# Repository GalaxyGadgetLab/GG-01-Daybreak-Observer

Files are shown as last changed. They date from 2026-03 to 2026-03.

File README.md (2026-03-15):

# 銀河ガジェット1号：黎明の観測者(Daybreak Observer)

>共に夜明けと新時代の幕開けを観測しようじゃないかッ!

## 概要
スピーカを搭載した親機を枕元に，停止用RFIDリーダを備えた子機をリビングに設置します．
アラーム時刻の設定は，同一ネットワーク内のデバイスからブラウザ経由で親機のWebサーバーへアクセスして行います．
リビングまで移動してラボの会員証(RFIDタグ)をかざさない限り，アラームは止まりません．

## 構成
## ハードウェア

### 親機(Parent Unit)
| Function | Component / Module | Interface |
| :--- | :--- | :--- |
| MCU | ESP32-WROOM-32E | - |
| Audio | DFPlayer Mini | UART |
| RTC | DS3231  | I2C |
| Display | 2.8"TFT(ILI9341) | SPI |

### 子機(Child Unit)
| Function | Component / Module | Interface |
| :--- | :--- | :--- |
| MCU | ESP32-WROOM-32E | - |
| RFID | MFRC522 (NFC Reader/Writer) | SPI |
| Indicator | High-brightness Red LED | GPIO |
| Alarm | Piezoelectric Buzzer | GPIO |

## PCB設計
本プロジェクトでは，専用のカスタム基板を設計・製作しました．
- **Design Tool：** KiCad 9.0
- **Layer:** 2 Layers

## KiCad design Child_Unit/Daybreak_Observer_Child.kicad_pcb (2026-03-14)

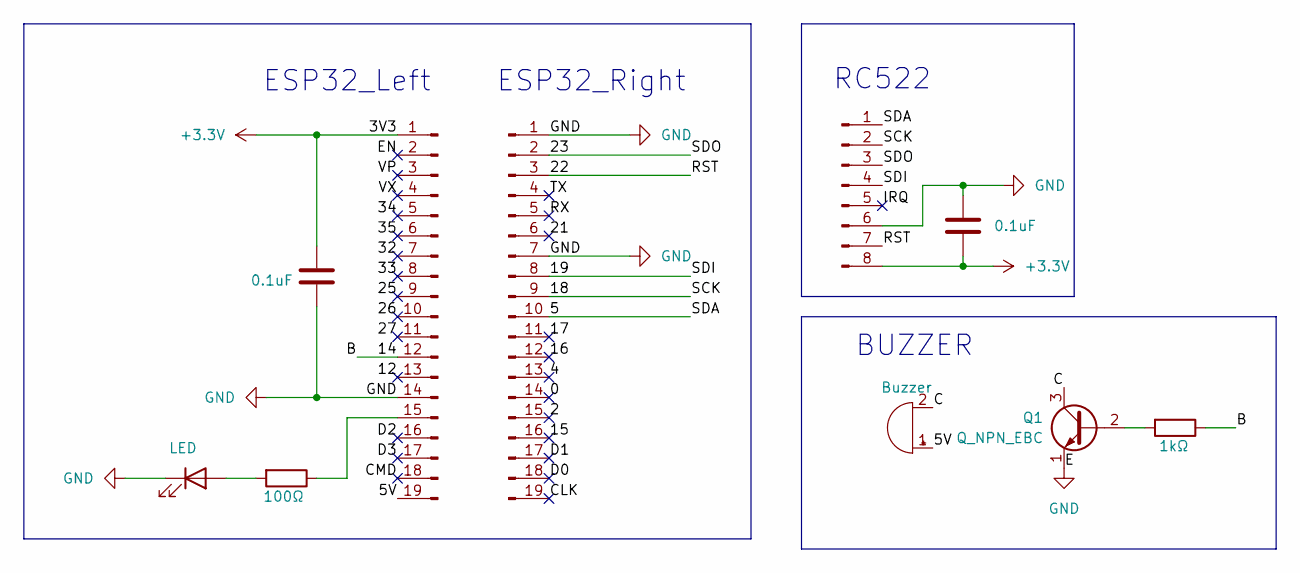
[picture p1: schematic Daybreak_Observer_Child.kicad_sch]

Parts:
BZ1: Buzzer; Buzzer_12x9.5RM7.6
C1, C2: 0.1uF; C_Disc_D5.0mm_W2.5mm_P2.50mm
D1: LED; LED_D3.0mm
J1, J2: Conn_01x19_Pin; PinSocket_1x19_P2.54mm_Vertical
J3: Conn_01x08_Pin; PinSocket_1x08_P2.54mm_Vertical
Q1: Q_NPN_EBC; TO-92_Inline
R2: 100Ω; R_Axial_DIN0207_L6.3mm_D2.5mm_P7.62mm_Horizontal
R3: 1kΩ; R_Axial_DIN0207_L6.3mm_D2.5mm_P7.62mm_Horizontal

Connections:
+3.3V: C1.1, C2.2, J1.1, J3.8
/0: J2.14
/2: J2.15
/4: J2.13
/5: J2.10, J3.1
/5V: BZ1.1 (+), J1.19
/12: J1.13
/14: J1.12, R3.1
/15: J2.16
/16: J2.12
/17: J2.11
/18: J2.9, J3.2
/19: J2.8, J3.4
/21: J2.6
/22: J2.3, J3.7
/23: J2.2, J3.3
/25: J1.9
/26: J1.10
/27: J1.11
/32: J1.7
/33: J1.8
/34: J1.5
/35: J1.6
/C: BZ1.2 (-), Q1.3 (C)
/CLK: J2.19
/CMD: J1.18
/D0: J2.18
/D1: J2.17
/D2: J1.16
/D3: J1.17
/EN: J1.2
/IRQ: J3.5
/RX: J2.5
/TX: J2.4
/VP: J1.3
/VX: J1.4
GND: C1.2, C2.1, D1.1 (K), J1.14, J2.1, J2.7, J3.6, Q1.1 (E)
unnamed: D1.2 (A), R2.2
unnamed: J1.15, R2.1
unnamed: Q1.2 (B), R3.2

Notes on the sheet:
RC522
BUZZER
ESP32_Left
ESP32_Right

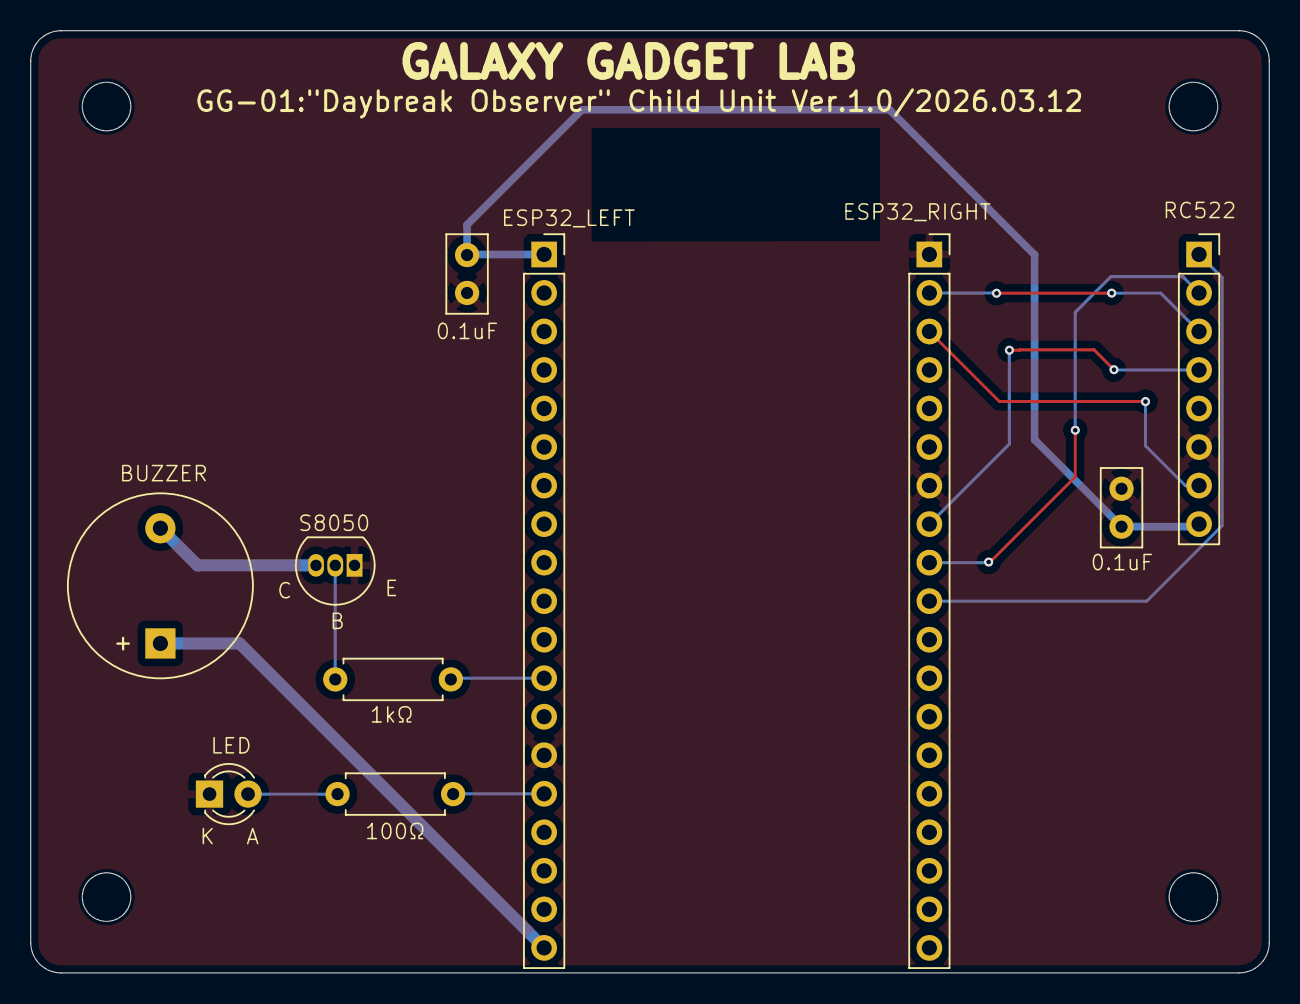
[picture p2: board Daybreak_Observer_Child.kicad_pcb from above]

Board: 2 copper layers, 81.7 x 62.1 mm, 10 parts (0 on the bottom side), 13 nets.

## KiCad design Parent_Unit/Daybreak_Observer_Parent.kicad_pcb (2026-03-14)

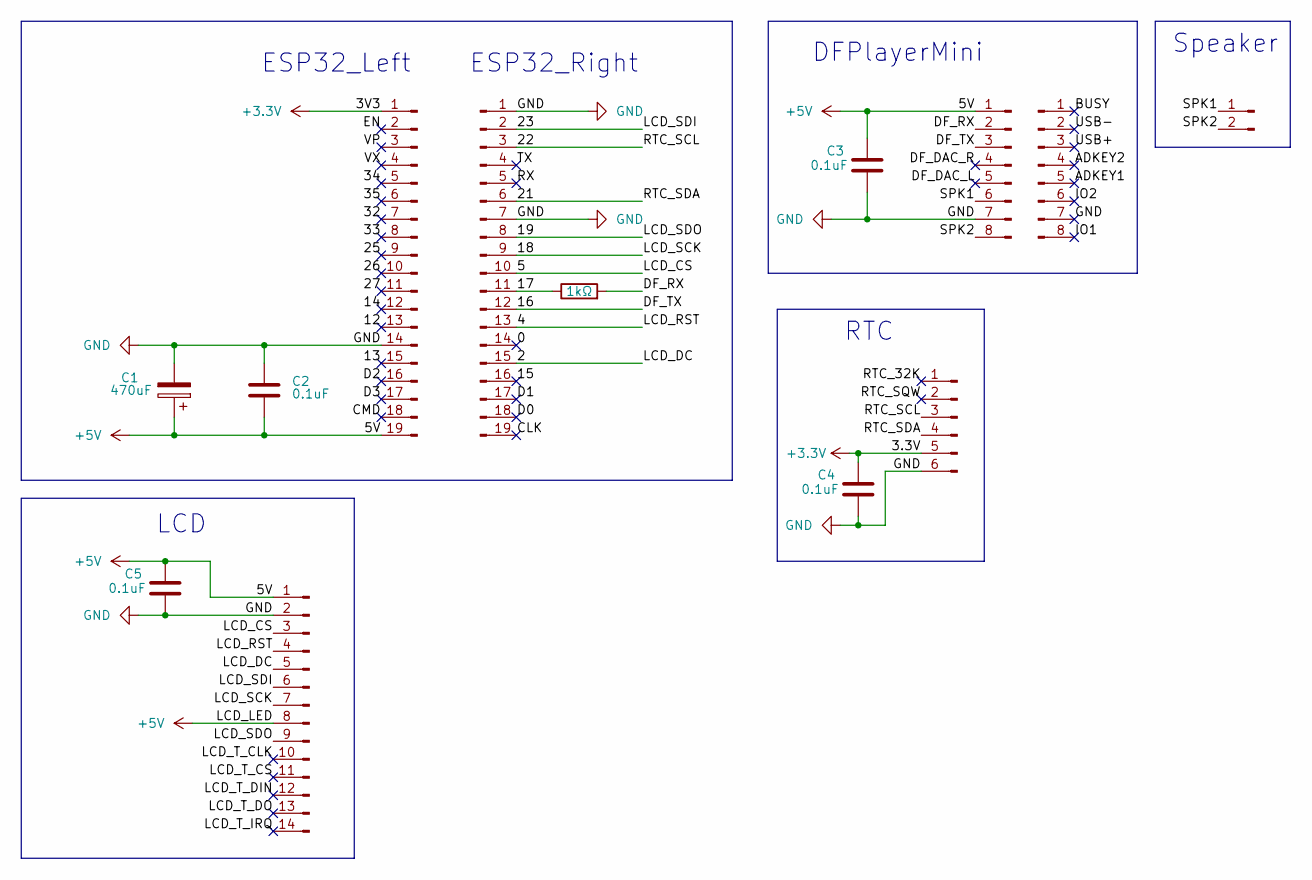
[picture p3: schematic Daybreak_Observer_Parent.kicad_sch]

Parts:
C1: 470uF; CP_Radial_D6.3mm_P2.50mm
C2, C3, C4, C5: 0.1uF; C_Disc_D5.0mm_W2.5mm_P2.50mm
J1, J2: Conn_01x19_Pin; PinSocket_1x19_P2.54mm_Vertical
J3, J4: Conn_01x08_Pin; PinSocket_1x08_P2.54mm_Vertical
J5: Conn_01x06_Pin; PinSocket_1x06_P2.54mm_Vertical
J6: Conn_01x14_Pin; PinSocket_1x14_P2.54mm_Vertical
J7: Conn_01x02_Pin; JST_PH_B2B-PH-K_1x02_P2.00mm_Vertical
R1: 1kΩ; R_Axial_DIN0207_L6.3mm_D2.5mm_P7.62mm_Horizontal

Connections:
+3.3V: C4.1, J1.1, J5.5
+5V: C1.1, C2.2, C3.1, C5.1, J1.19, J3.1, J6.1, J6.8
/0: J2.14
/2: J2.15, J6.5
/4: J2.13, J6.4
/5: J2.10, J6.3
/12: J1.13
/13: J1.15
/14: J1.12
/15: J2.16
/16: J2.12, J3.3
/17: J2.11, R1.1
/18: J2.9, J6.7
/19: J2.8, J6.9
/21: J2.6, J5.4
/22: J2.3, J5.3
/23: J2.2, J6.6
/25: J1.9
/26: J1.10
/27: J1.11
/32: J1.7
/33: J1.8
/34: J1.5
/35: J1.6
/ADKEY1: J4.5
/ADKEY2: J4.4
/BUSY: J4.1
/CLK: J2.19
/CMD: J1.18
/D0: J2.18
/D1: J2.17
/D2: J1.16
/D3: J1.17
/DF_DAC_L: J3.5
/DF_DAC_R: J3.4
/DF_RX: J3.2, R1.2
/EN: J1.2
/IO1: J4.8
/IO2: J4.6
/LCD_T_CLK: J6.10
/LCD_T_CS: J6.11
/LCD_T_DIN: J6.12
/LCD_T_DO: J6.13
/LCD_T_IRQ: J6.14
/RTC_32K: J5.1
/RTC_SQW: J5.2
/RX: J2.5
/SPK1: J3.6, J7.1
/SPK2: J3.8, J7.2
/TX: J2.4
/USB+: J4.3
/USB-: J4.2
/VP: J1.3
/VX: J1.4
GND: C1.2, C2.1, C3.2, C4.2, C5.2, J1.14, J2.1, J2.7, J3.7, J4.7, J5.6, J6.2

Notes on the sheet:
LCD
ESP32_Left
Speaker
RTC
ESP32_Right
DFPlayerMini

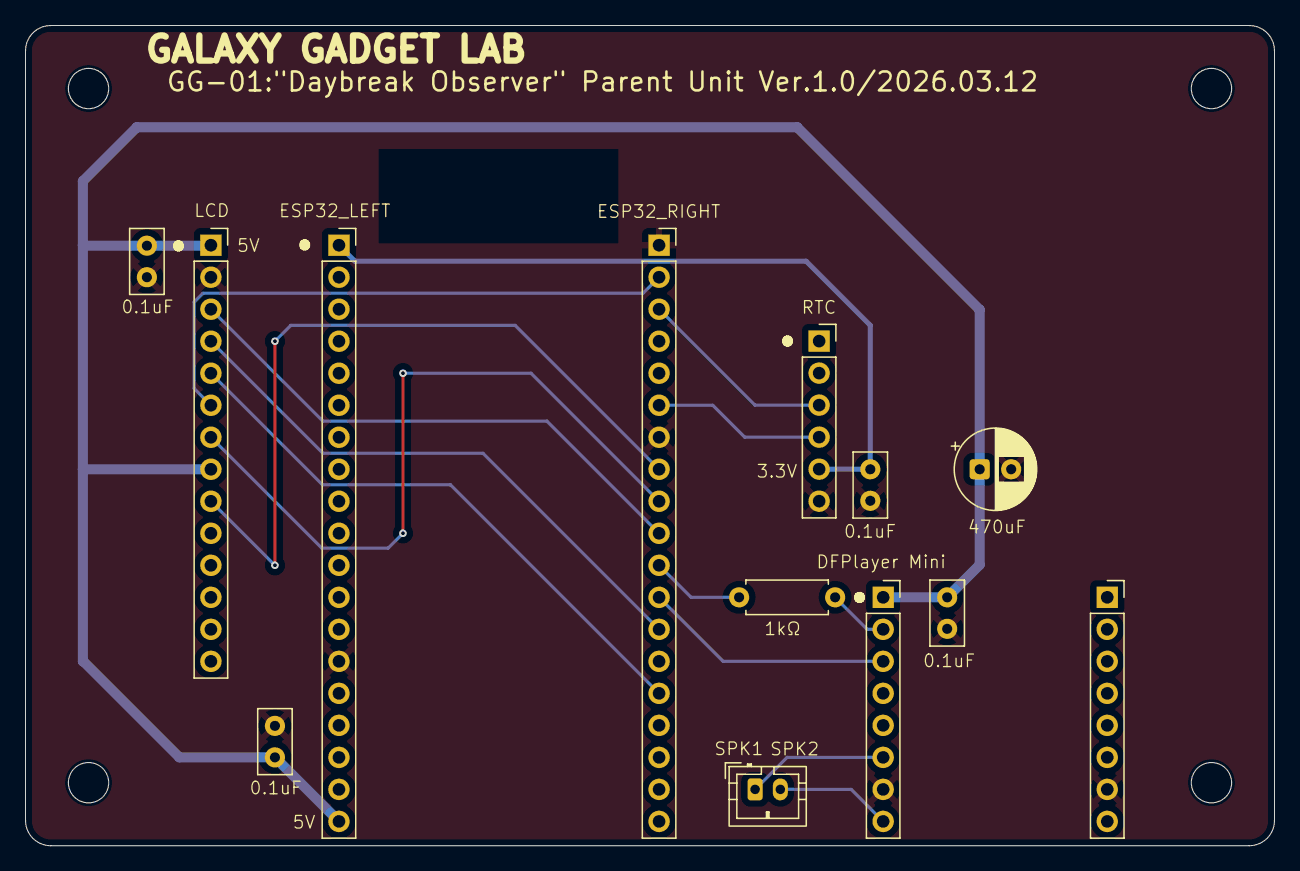
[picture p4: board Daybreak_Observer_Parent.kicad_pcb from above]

Board: 2 copper layers, 99.1 x 65.1 mm, 13 parts (0 on the bottom side), 16 nets.

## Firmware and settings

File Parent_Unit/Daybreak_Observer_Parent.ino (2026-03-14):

#include<Arduino.h>
#include<SPI.h>
#include<Adafruit_GFX.h>
#include<Adafruit_ILI9341.h>
#include<Fonts/FreeSans12pt7b.h>
#include<Fonts/FreeSans18pt7b.h>
#include<Fonts/FreeSans40pt7b.h>
#include<Wire.h>
#include<RTClib.h>
#include<time.h>
#include<HardwareSerial.h>
#include<DFRobotDFPlayerMini.h>
#include<WiFi.h>
#include<WebServer.h>
#include<HTTPClient.h>


//初期設定
const char *ssid="483E5E78354D-2G";
const char *pass="xx2pf9t9ctmthb";
IPAddress ip(192,168,3,101);
IPAddress gateway(192,168,3,1);
const char *notify_url="http://192.168.3.102/alarm";
const char *adjust_time="04:00:00";
#define DF_VOLUME 7


//定数
#define ALARM_SIG 25
#define TFT_DC 2             //液晶ディスプレイのDCピンをGPIO2に接続
#define TFT_CS 5             //液晶ディスプレイのCSピンをGPIO5に接続
#define TFT_RST 4            //液晶ディスプレイのRESETピンをGPIO4に接続
#define TFT_WIDTH 320        //液晶ディスプレイの幅320

Adafruit_ILI9341 tft=Adafruit_ILI9341(TFT_CS,TFT_DC,TFT_RST);
RTC_DS3231 rtc;
HardwareSerial hs(1);
DFRobotDFPlayerMini myDFPlayer;
WebServer server(80);   //WebServer型の変数server

char old_date[15];
char old_time[9];
char old_alarm[15];
char alarm_time[9];
char wdays[7][4]={"Sun","Mon","Tue","Wed","Thu","Fri","Sat"};
bool alarm_checked=false;
bool alarm_on=false;
bool ntp_adjusted=false;
int alarm_ctr;

//NTPで日時を設定
void setTimeByNTP(){
  struct tm tm;  //time.hで定義されているtm構造体
  
  configTime(9*3600L,0,"ntp.nict.jp","time.google.com","ntp.jst.mfeed.ad.jp"); //UTCとJSTの時差9*3600s
  if(!getLocalTime(&tm)){
    Serial.println("getLocalTime Error");
    return;
  }
           //time_t t=time(NULL);
           //localtime_r(&t,&tm);
  rtc.adjust(DateTime(tm.tm_year+1900,tm.tm_mon+1,tm.tm_mday,tm.tm_hour,tm.tm_min,tm.tm_sec));
  //rtc.adjust(DateTime(2022,4,18,0,30,0));
}

//現在の日時を液晶ディスプレイに表示(時間の進行に伴いディスプレイの表示を変化させる処理)
void showMessage(char* s_new,char* s_old,int y0,int height){
  int16_t x1,y1;
  uint16_t w, w2,h;
  int x,y;
  if(strcmp(s_new,s_old)!=0){     //新しく時刻を取得したら以下の処理を実行
    tft.getTextBounds(s_old,0,0,&x1,&y1,&w,&h);   //テキストサイズ取得
    w2=w*11/10;
    tft.fillRect((TFT_WIDTH-w2)/2,y0-(height/2)+1,w2,height,ILI9341_BLACK);   //黒で塗りつぶす
    tft.getTextBounds(s_new,0,0,&x1,&y1,&w,&h);
    tft.setCursor((TFT_WIDTH-w)/2,y0+(h/2)-1);    //テキスト表示位置を設定
    tft.print(s_new);
    strcpy(s_old,s_new);
  }
}

//設定メインページ
void handleRoot()
{
  int i;

  String html=
    "<!DOCTYPE html>\n"
    "<html>\n"
    "<head>\n"
    "<meta charset=\"utf-8\">\n"
    "<title>アラーム時計設定</title>\n"
    "</head>\n"
    "<body>\n"
    "<form method=\"get\" action=\"/set\">\n"
    "<p>\n"
    "<select name=\"hour\">\n";
  for(i=0;i<24;i++)
    {
    html+="<option value=\"";
    html+=String(i);
    html+="\">";
    html+=String(i);
    html+="</option>\n";
    }
  html+="</select>時\n";
  html+="<select name=\"min\">\n";
  for(i=0;i<60;i++)
    {
    html+="<option value=\"";
    html+=String(i);
    html+="\">";
    html+=String(i);
    html+="</optioon>\n";
    }
   html+="</select>分\n";
   html+="<input type=\"submit\" name=\"submit\" value=\"アラーム設定\" />\n";
   html+="</p>\n";
   html+="</form>\n";
   html+="<form method=\"get\" action=\"/set\">\n";
   html+="<input type=\"hidden\" name=\"off\" value=\"1\">\n";
   html+="</p><input type=\"submit\" name=\"submit\" value=\"アラームoff\" /></p>\n";
   html+="</form>";
   html+="</body>";
   html+="</html>";
   server.send(200,"text/html",html);
}

//アラームの設定
void handleSetAlarm()
{
  int i,hour,min,sec;
  bool is_off=false;
  String s_hour="",s_min="",s_sec="";

  //URLからoff/hour/min/secのパラメータを取得する
  for(i=0;i<server.args();i++)   //リクエストパラメータの数だけ繰り返す
  {
    if(server.argName(i).compareTo("off")==0)
    {
      is_off=true;
      break;
    }
    else if(server.argName(i).compareTo("hour")==0)
    {
      s_hour=server.arg(i);   //リクエストパラメータ名がhourのときのリクエストパラメータの値を代入
    }
    else if(server.argName(i).compareTo("min")==0)
    {
      s_min=server.arg(i);
    }
    else if(server.argName(i).compareTo("sec")==0)
    {
      s_sec=server.arg(i);
    }
  }

  //offのパラメータが設定されているとき,アラームをオフにする
  if(is_off)
  {
    strcpy(alarm_time,"Off");
    server.send(200,"text/plain, charset=utf-8","アラームをオフにしました.");
  }

  //アラームの時刻を設定する
  else if(s_hour.length()>0&&s_min.length()>0)
  {
    hour=s_hour.toInt();    //String型からint型へ変換
    min=s_min.toInt();
    if(s_sec.length()>0)
    {
      sec=s_sec.toInt();
    }
    else
    {
      sec=0;
    }

    if(hour>=0 && hour<=23 && min>=0 && min<=59 && sec>=0 && sec<=59)
    {
      sprintf(alarm_time,"%02d:%02d:%02d",hour,min,sec);
      String msg="アラームを ";
      msg.concat(alarm_time);
      msg.concat("に設定しました.");
      server.send(200,"text/plain; charset=utf-8",msg);   
                         // MIMEタイプ(ファイルの分類/ファイルの種類)
    }
    else
    {
      server.send(200,"text/plain; charset=utf-8","日時が正しくありません.");
    }
  }
  else
  {
     server.send(200,"text/plain; charset=utf-8","パラメータが正しくありません.");
  }  
}

//アラームを止める
void handleStopAlarm()
{
  myDFPlayer.pause();
  alarm_on=false;
  tft.drawRect(30,180,260,40,ILI9341_BLACK);    //短形を描画
  server.send(200,"text/plain","Alarm stop");
   ledcWrite(1,LOW);
   ledcWrite(2,LOW);
   ledcWrite(3,LOW);
}

//無効なURLが選択された場合
void handleNotFound()
{
  String Message="Not Found : ";
  Message+=server.uri();
  server.send(404,"text/plain","errorMessage");
}

//セットアップ
void setup(){
  int16_t x1,y1;
  uint16_t w,h;

  
 
   Serial.begin(115200);    //115200bpsでポートを開く

   strcpy(old_date,"00000000000000");
   strcpy(old_time,"00000000");
   strcpy(old_alarm,"00000000000000");
   strcpy(alarm_time,"Off");

   //ディスプレイの初期化
   tft.begin();
   tft.setRotation(3);    //ディスプレイの文字を90deg回転
   tft.fillScreen(ILI9341_BLACK);
   tft.setTextColor(ILI9341_YELLOW);
   tft.setFont(&FreeSans12pt7b);
   String s="Initializing...";
   tft.getTextBounds(s,0,0,&x1,&y1,&w,&h);
   tft.setCursor(0,h);
   tft.println(s);

  //WiFi接続
  WiFi.begin(ssid,pass);
 while(WiFi.status()!=WL_CONNECTED)
  {
    delay(500);
    Serial.print(".");
  }
  WiFi.config(ip,gateway,WiFi.subnetMask(),IPAddress(8,8,8,8));
      //8.8.8.8や8.8.4.4はGoogle Public DNSのIPアドレス
  Serial.print("");
  Serial.println("WiFi Connectid.");
  tft.println("WiFi Connected.");

  //DFPlayer初期化
  hs.begin(9600,SERIAL_8N1,16,17);
  int count=0;
  while(count<10)

  {
    if(!myDFPlayer.begin(hs))
    {
    count++;
    Serial.println("DFPlayer initialize attempt");
    Serial.print(count);
    }
    else
    {
      break;
    }
  }
  if(count<10)
  {
    Serial.println("DFPlayer Initialized.");
    tft.println("DFPlayer Initialized.");
    myDFPlayer.pause();
    myDFPlayer.volume(DF_VOLUME);
  }
  else
  {
    Serial.println("DFPlayer Error");
    tft.println("DFPlayer Error");    //カウントが10になるまでに準備できなければエラー
    while(1);
  }

  //RTC初期化
  if(!rtc.begin())
  {
    Serial.println("Could't find RTC");
    while(1);
  }

  Serial.println("RTC Initialized.");
  tft.println("RTC Initialized.");

  //NTPで現在時刻を取得してRTCに設定
  setTimeByNTP();

  //WebServer初期化
  server.on("/",handleRoot);
  server.on("/set",handleSetAlarm);
  server.on("/stop",handleStopAlarm);
  server.onNotFound(handleNotFound);
  server.begin();
      //それぞれ「/」,「/set」,「/stop」,それ以外にアクセスされたときに実行する関数を指定

  //ディスプレイを黒で塗りつぶす
  tft.fillScreen(ILI9341_BLACK);


}

void loop()
{
  char new_time[9],new_date[15],new_alarm[15];

  //Webサーバーを動作させる
  server.handleClient();

  //現在の時刻を液晶ディスプレイに表示 
  DateTime now=rtc.now();
  sprintf(new_date,"%04d/%02d/%02d ",now.year(),now.month(),now.day());
  strcat(new_date,wdays[now.dayOfTheWeek()]);
  sprintf(new_time,"%02d:%02d:%02d",now.hour(),now.minute(),now.second());
  strcpy(new_alarm,"Alarm ");
  strcat(new_alarm,alarm_time);
  tft.setFont(&FreeSans18pt7b);
  tft.setTextColor(ILI9341_GREEN);
  showMessage(new_date,old_date,40,28);
  showMessage(new_alarm,old_alarm,200,28);
  tft.setFont(&FreeSans18pt7b);
  showMessage(new_time,old_time,120,64);

  //現在の時刻がアラームの時刻になっているかどうかを判断
  if(strstr(new_time,alarm_time)!=NULL)
  {
    if(!alarm_checked)  //alarm_checkedで処理の重複を防ぐ
    {
      myDFPlayer.loop(1);
      alarm_checked=true;
      alarm_on=true;
      alarm_ctr=0;
      HTTPClient http;
      http.begin(notify_url);
      int httpCode=http.GET();
    }
  }
  else
  {
    alarm_checked=false;
  }

  //アラームが鳴っている間は,液晶ディスプレイのアラーム時刻の周りに赤枠を点滅させる
  if(alarm_on)
  {
    if(alarm_ctr==0)
    {
      tft.drawRect(30,180,260,40,ILI9341_RED);
    }
    else if(alarm_ctr==ALARM_SIG)
    {
      tft.drawRect(30,180,260,40,ILI9341_BLACK);
    }
    alarm_ctr++;
    alarm_ctr%=ALARM_SIG*2;  //alarm_ctrが1ずつ増加し,25のとき黒,50のとき余り0で赤
  
    long randNumber_R=0;
    long randNumber_G=0;
    long randNumber_B=0;

    randomSeed(analogRead(35));
    randNumber_R=random(0,256);

    randomSeed(analogRead(32));
    randNumber_G=random(0,256);
    
    randomSeed(analogRead(33));
    randNumber_B=random(0,256);

    int rgb[]={randNumber_R,randNumber_G,randNumber_B};
    ledcWrite(1,rgb[0]);
    ledcWrite(2,rgb[1]);
    ledcWrite(3,rgb[2]);
  }

  //毎日一定の時刻にNTPで時刻合わせを行う.
  if(strstr(new_time,adjust_time)!=NULL)
  {
    if(!ntp_adjusted)  //ntp_adjustedで処理の重複を防ぐ
    {
      setTimeByNTP();
      ntp_adjusted=true;
    }
  }
  else
  {
  ntp_adjusted=false;
  }

  delay(20);
}













 

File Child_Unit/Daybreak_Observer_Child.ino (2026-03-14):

#include<WiFi.h>
#include<WebServer.h>
#include<HTTPClient.h>
#include<SPI.h>
#include<MFRC522.h>

const char *ssid="483E5E78354D-2G";
const char *pass="xx2pf9t9ctmthb";
IPAddress ip(192,168,3,102);
IPAddress gateway(192,168,3,1);
const char* stop_url="http://192.168.3.101/stop";

#define SWITCH 4
#define LED 13
#define BUZZER 14
#define SS_PIN 5
#define RST_PIN 22
MFRC522 mfrc522(SS_PIN, RST_PIN);

bool is_alarm=false;

WebServer server(80);

//親機のアラームがONになったときの処理
void handleAlarm()
{
  is_alarm=true;
  digitalWrite(LED,HIGH);
  Serial.println("Alarm started");
  server.send(200,"text/plain","Alarm started");
}

//無効なURLが指定された場合
void handleNotFound()
{
  String messege="Not Found:";
  messege+=server.uri();
  server.send(404,"text/plain","messege");
}

void setup() {
  Serial.begin(115200);
  
  SPI.begin();
  mfrc522.PCD_Init();

  //GPIO設定
  pinMode(SWITCH,INPUT_PULLDOWN);
  pinMode(LED,OUTPUT);
  pinMode(BUZZER,OUTPUT);
  digitalWrite(LED,LOW);
  digitalWrite(BUZZER,LOW);

  //WiFi接続
  WiFi.begin(ssid,pass);
  while(WiFi.status()!=WL_CONNECTED)
  {
    delay(500);
    Serial.print(".");
  }
  WiFi.config(ip,gateway,WiFi.subnetMask(),IPAddress(8,8,8,8),IPAddress(8,8,4,4));
  Serial.println("");
  Serial.println("WiFi Connected.");

  //WebServerの初期化
  server.on("/alarm",handleAlarm);
  server.onNotFound(handleNotFound);
  server.begin();
}

void loop()
{
  //Webサーバを動作させる
  server.handleClient();

  if(is_alarm)
  {
     if(mfrc522.PICC_IsNewCardPresent() && mfrc522.PICC_ReadCardSerial())
     {
      Serial.println("RFID detected.");
      digitalWrite(BUZZER,HIGH);
      delay(100);
      digitalWrite(BUZZER,LOW);
      digitalWrite(LED,LOW);

      HTTPClient http;
      http.begin(stop_url);
      int httpCode=http.GET();
      http.end();

      is_alarm = false;

      mfrc522.PICC_HaltA();       // カードとの通信を終了
      mfrc522.PCD_StopCrypto1();  // リーダーの暗号化通信を停止

      delay(500);
     }
  }
}
